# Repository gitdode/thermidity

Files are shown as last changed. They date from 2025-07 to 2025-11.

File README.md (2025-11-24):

# Thermidity



AVR MCU based battery powered thermometer and hygrometer with e-ink display.  
Focus is on stable, accurate measurements and low power consumption. 
And of course on a nice, simple display.

The project is based on [avrink](https://github.com/gitdode/avrink) and uses the
following components:

* MCU AVR ATmega328P
* Thermistor NTC 100kΩ 0.1°C
* Humidity Sensor HIH-5030
* E-Ink display Adafruit Monochrome 2.13" 250x122
    * Driver SSD1680
    * SRAM 23K640
    * SD Card Reader (not used)
 
Thanks to https://github.com/sprintersb for helping me to improve the code and making it more efficient!

Thermidity-07

## Accuracy

AD conversion is done with 16x oversampling, yielding 12-bit virtual resolution 
with the 10-bit ADC, provided the signal contains some noise.

Each time measurements were taken, a moving average is updated which is used to 
calculate and display temperature, humidity and battery voltage.

A precision thermistor and precision low-voltage humidity sensor are used:

| Component  | Accuracy |
|---|---:|
| Thermistor |  ¹±0.1°C |
| HIH-5030 | ±3%RH |

¹Series resistor 0.1% tolerance

## Power Consumption

Estimated average power consumption is about 30µA when measuring every 32 
seconds and updating the display once in about 5 minutes, hopefully giving an
operating time of about 3 years with 3 AAA batteries (1100 mAh, 6% 
self-discharge). 

The consumption of each component at 3.8V and 22°C is about:

| Component  | Data Sheet | Measured |
|---|---:|---:|
| ATmega328P | ¹4.2µA | 4.5µA |
| Thermistor | N/A | 24µA |
| HIH-5030 | ²200µA | 211µA |
| V-Divider  | N/A | 2µA |
| Display | ³N/A | 14µA |

¹VCC = 3V, power-down sleep mode  
²VCC = 3.3V  
³Display in deep sleep mode + SRAM + SD Card Reader + Bus Transceiver  

Between taking measurements, the MCU is set to power-down sleep mode with the
watchdog used as wake-up source. Additionally, the thermistor and humidity 
sensor are powered off and between display updates, the display is set to deep 
sleep mode. Power consumption (measured) then is about 19µA at 3.8V for MCU 
and display.  

When measuring temperature, humidity and battery voltage in ADC noise reduction 
mode, consumption seems to be somewhere around 2mA for 6ms, plus a brief 
additional MCU awake period for updating the moving average with measured 
values. Before measuring, the sensors are powered on and given 100ms to settle, 
consuming about 240µA.

When updating the display, consumption is at around 6mA for about 3 seconds. 
Before that, the MCU has to calculate and format the average measurements and 
buffer the frame in SRAM.

The display is updated in fast update mode, taking 1.5s instead of 3s for full 
update mode, saving a considerable amount of power. To avoid ghosting effects, 
every 10th update is a full update.

When no measurement has changed, the display is not updated at all to extend its 
lifetime and to save more power.

Below the cutoff voltage of 3.0V, the watchdog is disabled to stop measuring and
updating the display, to at least delay total discharge of the batteries.
Consumption of the MCU then is at about 1µA and 19µA of the display.

The clock of unused modules TWI, all three timers and USART is switched off to 
reduce power consumption.

Disabling the ADC between measurements and the SPI between display updates both 
contributes to a significant reduction of power consumption. With an enabled SPI, 
consumption of the display including its peripheral is extremely unstable and 
varies between some tens of microamps and several milliamps. When driving the 
enable pin of the display low, consumption is stable at about 60µA. When not 
driving the enable pin low and disabling SPI (driving SCK pin low) consumption 
is at about 14µA.

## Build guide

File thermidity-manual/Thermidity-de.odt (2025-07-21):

Thermidity

Batteriebetriebenes Thermometer und Hygrometer

# Beschreibung

Thermidity ist ein einfaches Thermometer und Hygrometer bei dessen Entwicklung besonderer Wert auf ein gut ablesbares Display, hohe Messgenauigkeit, geringen Stromverbrauch und die Verwendung möglichst weniger aber dafür hochwertiger Bauteile gelegt wurde.

Die Software kann aktualisiert werden, wodurch zukünftige Anpassungen und Verbesserungen möglich sind.

Alle verwendeten Bauteile sind RoHS konform.
Bei der Herstellung dieses Thermometers wurde bleifreies Lot verwendet.

Made with 💜 by Dode

# Komponenten

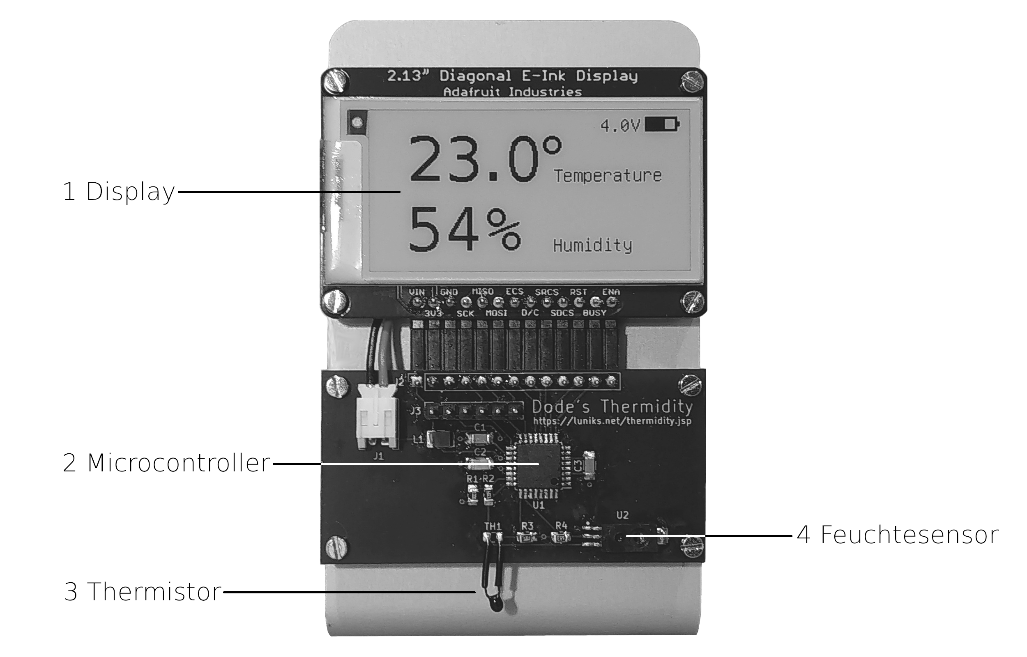
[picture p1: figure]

1. Display Adafruit Monochrome 2.13" 250x122
2. Microcontroller Atmel/Microchip AVR ATmega328P
3. Thermistor (Temperaturfühler) NTC 100kΩ 0.1°C
4. Feuchtesensor Honeywell HIH-5030

# Inbetriebnahme

⚠
Beim Einlegen der Batterien darauf achten, dass kein Druck auf das Display und die übrigen Bauteile ausgeübt wird und der Temperaturfühler nicht beschädigt oder verbogen wird.

1. Deckel des Batteriefachs durch leichten Druck unten auf die Riffelung und gleichzeitiges Schieben nach oben entfernen
2. Batterien einlegen, dabei auf richtige Polung achten
3. Deckel auf das Fach legen und durch leichten Druck auf die Riffelung und gleichzeitiges Schieben nach unten schließen
4. Nach ca. 1,5 Sekunden wird die aktuelle Temperatur und Luftfeuchtigkeit angezeigt
5. Das Thermometer an einem Ort aufstellen an dem es nicht Nässe oder über längere Zeit direkter Sonneneinstrahlung ausgesetzt ist

⚠
Beim Aufstellen des Thermometers bitte darauf achten, dass die Oberfläche von empfindlichen Möbeln nicht von den Kanten des Aluminiumrahmens verkratzt wird.

# Technische Daten

Parameter | Wert
Betriebsspannung | 3 – 5V
Betriebstemperatur | 0 – 50°C
Durchschnittlicher Stromverbrauch | ca. 30µA
Betriebsdauer mit Alkali-Mangan Batterien AAA/Micro¹ | ca. 3 Jahre
Genauigkeit Temperaturmessung | ±0,1°C
Genauigkeit relative Luftfeuchtigkeitsmessung | ±3%
Messbereich Temperatur² | -40 – +99,9°C
Messbereich Luftfeuchtigkeit | 0 – 99%
Messintervall | ca. 32 Sek.
Aktualisierungsintervall | ca. 5 Min.
Displayauflösung | 250 x 122 Pixel
Prozessortakt | 8 MHz

¹ Bei Verwendung von Akkus kann die Betriebsdauer wegen der geringeren Zellspannung und ggf. geringeren Kapazität sowie der höheren Selbstentladung kürzer ausfallen.

² Einschränkung der Betriebstemperatur auf 0 – 50°C ist durch das Display bedingt. Die Aufbewahrungstemperatur beträgt -25 – +70°C.

# Technische Details

Die Messung von Temperatur und Luftfeuchtigkeit erfolgt ca. alle 32 Sekunden ratiometrisch über einen 10-bit Analog-Digital Wandler. Durch 16-faches Oversampling wird eine virtuelle Auflösung von 12 Bit erreicht.

Mit jeder Messung wird ein gleitender Mittelwert aktualisiert, aus dem ca. alle 5 Minuten der Messwert berechnet und mit dem Ergebnis die Anzeige aktualisiert wird.

Für geringeren Stromverbrauch wird das Display im Schnellmodus aktualisiert. Jede zehnte Aktualisierung wird jedoch ein vollständiges Update durchgeführt, um ein bei niedrigen Temperaturen eventuell auftretendes „Geisterbild“ zu beseitigen.
Hat sich seit der letzten Aktualisierung kein Messwert geändert, wird die Anzeige nicht unnötig aktualisiert, was neben einer zusätzlichen Verringerung des Stromverbrauchs die Lebensdauer des Displays verlängert.

Um den Stromverbrauch weiter zu reduzieren, werden die Sensoren zwischen den Messungen abgeschaltet. Der Prozessor wird zudem in einen Schlafmodus versetzt und in regelmäßigen Abständen von einem Wachhund aufgeweckt.

Sinkt die Batteriespannung unter das Minimum von 3V, wird der Wachhund in Ruhestand geschickt. Der Prozessor wird dann nicht mehr aufgeweckt und führt daher keine weiteren Messungen und Aktualisierungen der Anzeige durch. Mit der dabei erreichten Verringerung des Stromverbrauchs wird eine schädliche Tiefentladung von Akkus erheblich hinausgezögert.

⚠
Da keine vollständige Abschaltung erfolgt und ein Ruhestrom von ca. 20µA verbleibt, sollten leere Batterien und Akkus bald ersetzt bzw. wieder aufgeladen werden.

# Vergleich mit anderen Thermometern und Hygrometern

Beim direkten Vergleich der Messwerte dieses Thermometers mit z.B. handelsüblichen „Wetterstationen“ kann es zu Abweichungen kommen. Die Ursachen dafür können sein:

- Das Vergleichsgerät ist ungenau: Die Genauigkeit von Wetterstationen beträgt oft nur ±0,5 – 1°C Temperatur und z.T. mehr als ±5% relative Luftfeuchtigkeit. Dabei sei bemerkt dass Feuchtesensoren mit hoher Genauigkeit, wie in diesem Gerät verwendet, sehr teuer sind.
- Unterschiedliche Empfindlichkeit: Da sich bei diesem Thermometer die Sensoren nicht in einem Gehäuse befinden, reagiert es möglicherweise empfindlicher auf z.B. Zugluft als andere Geräte.
- Unterschiedliches Aktualisierungsintervall der Anzeige: Bei diesem Thermometer wird die Anzeige nur ca. alle 5 Minuten aktualisiert.

# Problembehebung

Problem | Ursache | Lösung
Anzeige wird nicht aktualisiert | Batterien leer (<= 3.0V) | Batterien ersetzen/Akkus aufladen
Anzeige ist grau und verwaschen | Batterien leer (<= 3.0V) | Batterien ersetzen/Akkus aufladen
Angezeigte Luftfeuchtigkeit beträgt +99% | Kondensation durch spontanen Temperatur-anstieg | Gerät akklimatisieren lassen
Gerät ist nass geworden | | Batterien entfernen und Gerät trocknen lassen
Gerät ist eingefroren | | Batterien entfernen und Gerät auftauen und trocknen lassen

# Sicherheitshinweise

Das Thermometer ist nicht spritzwassergeschützt und eignet sich daher nicht für den Betrieb in der Nähe von z.B. Waschbecken.

Das Thermometer nicht dauerhaft direkter Sonneneinstrahlung aussetzen. Die Funktion des Displays kann dadurch bleibend beeinträchtigt werden.

⚠
Das Display besteht aus Glas. Vorsicht Verletzungsgefahr bei Beschädigungen.
Sollte das Display zerbrechen, Kontakt mit ggf. austretender Flüssigkeit vermeiden. Bei Kontakt mit Wasser und Seife abwaschen.

# Referenzen

Email: torsten.roemer@luniks.net

Webseite: https://luniks.net/thermidity.jsp

Quellcode: https://github.com/gitdode/thermidity

Thermidity 2023-07-31 – Seite 8

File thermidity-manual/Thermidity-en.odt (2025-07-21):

Thermidity

Battery powered Thermometer and Hygrometer

# Description

Thermidity is a simple thermometer and hygrometer. During its development, particular effort was made for good readability of the display, high accuracy, low power consumption and using few but high-quality components.

The ability to update the software allows for future adjustments and improvements.

All components used are RoHS compliant.
Lead-free solder was used in the production of this thermometer.

Made with 💜 by Dode

# Components


1. Display Adafruit Monochrome 2.13" 250x122
2. Microcontroller Atmel/Microchip AVR ATmega328P
3. Thermistor (Temperature Sensor) NTC 100kΩ 0.1°C
4. Humidity Sensor Honeywell HIH-5030

# Usage

⚠
Make sure not to apply pressure on the display and the other components and not to damage or bend the temperature sensor when inserting the batteries.

1. Open the battery case by slightly pressing on the markings at the bottom and sliding the cover upwards
2. Insert the batteries, observe the polarity
3. Place the cover on the case and close it by slightly pressing on the markings and sliding it downwards
4. After about 1.5 seconds the current temperature and humidity is displayed
5. Place the thermometer at a location where it is not exposed to moisture or direct sunlight for longer periods of time

⚠
When placing the thermometer, please take care not to scratch the surface of delicate furniture with the edges of the aluminium frame.

# Technical Specification

Parameter | Value
Operating Voltage | 3 – 5V
Operating Temperature | 0 – 50°C
Average Power Supply Current | about 30µA
Operating Time with alkaline battery AAA/Micro¹ | about 3 years
Accuracy Temperature Measurement | ±0.1°C
Accuracy relative Humidity Measurement | ±3%
Measuring Range Temperature² | -40 – +99.9°C
Measuring Range Humidity | 0 – 99%
Measuring Interval | about 32 sec.
Update Interval | about 5 min.
Display Resolution | 250 x 122 Pixel
CPU Clock | 8 MHz

¹ Operating time can be shorter when using rechargeable batteries because of the lower voltage and possibly lower capacity, and the higher self-discharge.

² Operation temperature is limited to 0 – 50°C by the display. Storage temperature is -25 – +70°C.

# Technical Details

Measurement of temperature and humidity is done about every 32 seconds ratiometrically with a 10-bit analogue digital converter and 16-times oversampling, yielding a virtual resolution of 12 Bit.

A moving average is updated with each measurement. About every 5 minutes, the measurement values are calculated from that average, and the display is updated with the result.

To reduce power consumption, the display is updated in fast mode. Each 10th update however, a full update is done to remove ghosting that can possibly occur at low temperatures.
If no measurement value changed since last update, the display is not updated unnecessarily to further reduce power consumption and extend the lifetime of the display.

For additional reduction of power consumption, the sensors are switched off between measurements, and the CPU is put to sleep mode and woken up by a watchdog at a regular interval.

When the battery voltage goes below a minimum of 3V, the watchdog is retired so the CPU is not woken up any more and thus does not perform further measurements and display updates. With the achieved reduction of power consumption, a harmful total discharge of rechargeable batteries is delayed significantly.

⚠
Because the device is not powered down completely and an idle current of about 20µA remains, empty (rechargeable) batteries should soon be replaced or recharged, respectively.

# Comparison with other Thermometers and Hygrometers

Direct comparison of the measurement values of this thermometers with for example commercially available “Weather Stations” can reveal a certain deviation. Causes for this can be:

- The device used for comparison is inaccurate: The accuracy of weather stations commonly is only ±0.5 – 1°C temperature and sometimes more than ±5% relative Humidity. It should be noted that humidity sensors with high accuracy, as used in this device, are very expensive.
- Different sensitivity: The sensors of this thermometer are not inside a case, so it is possibly more sensitive to for example draught as other devices.
- Different display update interval: This thermometer updates the display only about every 5 minutes.

# Troubleshooting

Problem | Cause | Solution
Display is not updated | Batteries weak (<= 3.0V) | Replace/recharge batteries
Display is greyish and blurry | Batteries weak (<= 3.0V) | Replace/recharge batteries
Humidity displayed is +99% | Condensation caused by spontaneous rise of temperature | Let the device acclimate itself
Device is wet | | Remove batteries and let the device dry
Device is frozen | | Remove batteries and let the device thaw and dry

# Safety Notes

The thermometer is not splash proof and therefore not suitable to be operated close to for example a bathroom sink.

Do not expose the thermometer to direct sunlight for long periods of time as this can cause degraded performance of the display.

⚠
The display is made of glass. Attention risk of injury when damaged.
Should the display break, avoid contact with possibly leaking liquid. In case of contact, wash with water and soap.

# References

Email: torsten.roemer@luniks.net

Website: https://luniks.net/thermidity.jsp

Source code: https://github.com/gitdode/thermidity

Thermidity 2023-07-31 – Page 8

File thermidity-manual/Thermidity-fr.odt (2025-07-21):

Thermidity

Thermomètre et hygromètre à piles

# Description

Thermidity est un simple thermomètre et hygromètre. Au cours de son développement, un effort particulier a été fait pour une bonne lisibilité de l'affichage, une grande précision, une faible consommation d'énergie et l'utilisation de composants peu nombreux mais de haute qualité.

La possibilité de mettre à jour le logiciel permet de futurs ajustements et améliorations.

Tous les composants utilisés sont conformes RoHS.
Une soudure sans plomb a été utilisée dans la fabrication de ce thermomètre.

Made with 💜 by Dode

La traduction de l'anglais a été faite avec l'aide de Google Translate.

# Composants


1. Écran Adafruit Monochrome 2.13" 250x122
2. Microcontrôleur Atmel/Microchip AVR ATmega328P
3. Thermistance (capteur de température) NTC 100kΩ 0,1°C
4. Capteur d'humidité Honeywell HIH-5030

# Usage

⚠
Assurez-vous de ne pas appliquer de pression sur l'écran et les autres composants et de ne pas endommager ou plier le capteur de température lors de l'insertion des piles.

1. Ouvrez le boîtier de piles en appuyant légèrement sur les marques en bas et en faisant glisser le couvercle vers le haut
2. Insérez les piles, respectez la polarité
3. Placez le couvercle sur le boîtier et fermez-le en appuyant légèrement sur les marques et en le faisant glisser vers le bas
4. Après environ 1,5 seconde, la température et l'humidité actuelles s'affichent
5. Placez le thermomètre à un endroit où il n'est pas exposé à l'humidité ou à la lumière directe du soleil pendant de longues périodes

⚠
Lorsque vous placez le thermomètre, veillez à ne pas rayer la surface des meubles délicats avec les bords du cadre en aluminium.

# Spécifications techniques

Paramètre | Valeur
Voltage de fonctionnement | 3 – 5V
Température de fonctionnement | 0 – 50°C
Courant d'alimentation moyen | env. 30µA
Autonomie avec pile alcaline AAA/Micro¹ | env. 3 ans
Précision de mesure de température | ±0,1°C
Précision de mesure de humidité relative | ±3%
Plage de mesure de température² | -40 – +99,9°C
Plage de mesure de humidité | 0 – 99%
Intervalle de mesure | env. 32 sec.
Intervalle de mise à jour | env. 5 min.
Résolution d'affichage | 250 x 122 pixels
Horloge du processeur | 8 MHz

¹ Le temps de fonctionnement peut être plus court lors de l'utilisation de piles rechargeables en raison de la voltage plus faible et éventuellement de la capacité inférieure, ainsi que de l'autodécharge plus élevée.

² La température de fonctionnement est limitée à 0 – 50°C par l'affichage. La température de stockage est de -25 à +70°C.

# Détails techniques

La mesure de la température et de l'humidité est effectuée environ toutes les 32 secondes de manière ratiométrique avec un convertisseur numérique analogique 10 bits et un suréchantillonnage 16 fois, ce qui donne une résolution virtuelle de 12 bits.

Une moyenne mobile est mise à jour à chaque mesure. Toutes les 5 minutes environ, les valeurs de mesure sont calculées à partir de cette moyenne et l'affichage est mis à jour avec le résultat.

Pour réduire la consommation d'énergie, l'affichage est mis à jour en mode rapide. Cependant, chaque 10e mise à jour, une mise à jour complète est effectuée pour supprimer les images fantômes qui peuvent éventuellement se produire à basse température.

Si aucune valeur de mesure n'a changé depuis la dernière mise à jour, l'affichage n'est pas mis à jour inutilement pour réduire la consommation d'énergie et prolonger la durée de vie de l'affichage.

Pour une réduction supplémentaire de la consommation d'énergie, les capteurs sont éteints entre les mesures et le processeur est mis en mode veille et réveillé par un chien de garde à intervalles réguliers.

Lorsque la voltage des piles descend en dessous d'un minimum de 3V, le chien de garde est envoyé à la retraite afin que le CPU ne soit plus réveillé et n'effectue donc plus de mesures et de mises à jour d'affichage. Avec la réduction obtenue de la consommation d'énergie, une décharge totale nocive des piles rechargeables est retardée de manière significative.

⚠
Parce que l'appareil n'est pas complètement éteint et qu'il reste un courant de repos d'environ 20µA, les piles (rechargeables) vides doivent bientôt être remplacées ou rechargées.

# Comparaison avec d'autres Thermomètres et Hygromètres

Une comparaison directe des valeurs de mesure de ces thermomètres avec, par exemple, des «stations météorologiques» disponibles dans le commerce peut révéler un certain écart. Les causes peuvent être :

- L'appareil utilisé pour la comparaison est imprécis : La précision des stations météo n'est généralement que de ±0,5 – 1°C de température et parfois plus de ±5% d'humidité relative. Il convient de noter que les capteurs d'humidité de grande précision, tels qu'utilisés dans cet appareil, sont très coûteux.
- Sensibilité différente : les capteurs de ce thermomètre ne sont pas à l'intérieur d'un boîtier, il est donc peut-être plus sensible, par exemple, aux courants d'air que d'autres appareils.
- Intervalle de mise à jour de l'affichage différent : Ce thermomètre ne met à jour l'affichage qu'environ toutes les 5 minutes.

# Dépannage

Problème | Cause | Solution
L'affichage n'est pas mis à jour | Piles faibles (<= 3.0V) | Remplacer/recharger les piles
L'affichage est grisâtre et flou | Piles faibles (<= 3.0V) | Remplacer/recharger les piles
L'humidité affichée est de +99% | Condensation causée par une élévation spontanée de la température | Laissez l'appareil s'acclimater
L'appareil est mouillé | | Retirez les piles et laissez sécher l'appareil
L'appareil est gelé | | Retirez les piles et laissez dégeler et sécher l'appareil

# Consignes de sécurité

Le thermomètre n'est pas étanche aux éclaboussures et ne peut donc pas être utilisé à proximité, par exemple, d'un lavabo.

N'exposez pas le thermomètre à la lumière directe du soleil pendant de longues périodes car cela peut entraîner une dégradation des performances de l'affichage.

⚠
L'écran est en verre. Attention risque de blessure en cas d'endommagement. En cas de bris de l'affichage, évitez tout contact avec un liquide susceptible de fuir. En cas de contact, laver avec de l'eau et du savon.

# Références

Courriel : torsten.roemer@luniks.net
Site Web : https://luniks.net/thermidity.jsp
Code source : https://github.com/gitdode/thermidity

Thermidity 2023-07-31 – Page 8

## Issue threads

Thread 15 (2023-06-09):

Try ratiometric measurement

gitdode, 2023-06-09:
- humidity sensor is ratiometric
- use a thermistor instead of TMP36
- no need for a reference voltage; use ATmega's internal 1.1V reference to measure battery voltage
- neither humidity sensor nor thermistor (?) require a bypass capacitor so MCU output pin can easily switch their supply current

Closed 2023-06-11.

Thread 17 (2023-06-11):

Replace temperature sensor with thermistor

gitdode, 2023-06-11:

Closed 2023-06-13.

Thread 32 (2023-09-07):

Problems with `Makefile`

sprintersb, 2023-09-07:
`Makefile`
---
* Option `-D__AVR_ATmega328P__` should be removed. This is a built-in define, and provided by `specs-atmega328p` since v5. If the compiler does not work as expected without defining that macro by hand, the toolchain is broken.
* Option `-Wl,--relax` bypasses the assembler and should be replaced by `-mrelax`. Otherwise, the assembler might compute symbol values / offsets at assembly time, but which are actually not computable at assembly time because linker relaxation might change their values.
* `thermidity.elf` depends on header files like `font.h`, which is not described in the current Makefile. This means that when you only change some header(s) and then rerun `make`, it won't re-build `thermidity.elf`.

gitdode, 2023-09-07:
- I've added `__AVR_ATmega328P__` so the Makefile based project configuration in NetBeans is also aware of the MCU. I might have to use manual configuration instead because of https://github.com/apache/netbeans/discussions/6421 and then I guess I can remove `__AVR_ATmega328P__` from the Makefile.
- Replaced `-Wl,--relax` with `-mrelax`.
- Checking how to do that...

sprintersb, 2023-09-08:
> NetBeans is also aware of the MCU
Ah, makes sense. I don't use NetBeans. Years ago I used it with Java and the experience was very good. But I tries several times to installit on Linux but was never successful :-(

> Checking how to do that...
One way is to add a dependency without a rule:
```
$(TARGET).elf: foo.h bar.h bazz.h ... Makefile

gitdode, 2023-09-09:
It was possible to remove `__AVR_ATmega328P__` from the Makefile and get rid of the false error markers caused by `__flash` with project configuration type 'Application' instead of 'Makefile', allowing to freely set 'Preprocessor Definitions', where I could simply add `__AVR_ATmega328P__` and `__flash=volatile` which of course is plain wrong but calms down 'Code Assistance' and all is fine in the editor. And of course the code is built with the Makefile as usual.

I like NetBeans quite a lot, it is very good in handling very large Java projects and works very well with Maven. And since it is under the roof of the Apache Software Foundation it advances very well. My colleagues all use IntelliJ but I just like to work with Open Source software :)

Closed 2023-09-08.

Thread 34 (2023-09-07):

Try to go to sleep mode during sensor power-on settling time

gitdode, 2023-09-07:
Instead of

`_delay_ms(100);`

could just

```
set_sleep_mode(SLEEP_MODE_PWR_DOWN);
sleep_mode();
```
and get woken up by watchdog after 1 second. The sensors certainly don't mind to have 1s instead of 100ms to settle.

Power consumption should be 1s * ~250uA vs. 100ms * ~6mA.

To be tested & measured.

gitdode, 2023-09-09:
Works but contributes to ~5-10% more power consumption. Power consumption of the MCU appears to be much lower than 6mA during `_delay_ms()`? To be measured.

Closed 2023-09-09.

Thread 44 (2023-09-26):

Use pointer-to-const when a function is not supposed to change a pointed-to object (like with String outputters)

sprintersb, 2023-09-26:
In functions like `sram::sramWriteString`, `display::writeString` and `uart::printString` that get a (pointer-to) string argument, the pointed-to object should be `const` because these functions are not supposed to change the pointed-to object.

For example, `usart::printString` should have prototype

`void printString (const char *data)` (or `void printString (const char *const data)` if you wish).

Notice that it makes a difference on which side of the `*` the `const` is placed:

* Left of the `*`, the `const` refers to the pointed-to object.
* Right of the `*`, the `const` refers to the pointer itself, i.e. to `data` in the example.

In most cases, it is fine to change pointers like `data`, e.g. by using them to iterate over the chars in a string, whereas for output functions like above, they should still work as expected and without diagnostic in contexts like:

```c++
const char text[] = "Hallo";
printString (text);
```

As a aside, this applies to other qualifiers like `volatile` or `__flash` as well, and also to pointers of higher order:

In `volatile int *p;`, `p` points to a volatile object but `b` itself is not volatile, whereas in `int * volatile p;`, `p` itself is volatile but the pointed-to object is not, and in `volatile int * volatile p;`, both `p` and the pointed-to object are volatile.

In `int **p;` there are 8 = 2<sup>3</sup> possible ways to put `volatile`'s.

Closed 2023-10-06.

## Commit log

2023-10-24 Auto-generate lookup tables for unifont.c and dejavu.c. The generated lookup tables are included by these C files and pointed-to by the new field Font.code_to_id which has type const __flash uint8_t*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
    font.c::getGlyphAddress() uses the lookup table to speed up glyph lookup,
    provided font->code_to_id is non-NULL -- which is always the case for now.
    This means that the binary search in getGlyphAddress() is actually dead code.
    The type of Font.code has been changed from uint16_t to code_t, which
    makes it easier to switch char codes from a 16-bit type to an 8-bit type.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
2025-03-27 Update estimated average power consumption
    Guessing 3 years with about 3.9V after 20 months and 4.8 -> 3.0V
2025-03-27 Update Makefile
    ...so project builds with GCC 14 on current Debian Linux
2025-07-21 Correction of manuals
    - average power consumption 30µA
    - operating time about 3 years
    - display resolution 250x122 pixel
